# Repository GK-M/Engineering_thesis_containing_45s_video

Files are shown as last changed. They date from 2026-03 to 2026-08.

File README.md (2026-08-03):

# Diploma Thesis Repository

**Project and Implementation of a Microprocessor Platform for Building Distributed I/O Using a Selected Protocol Supported by Siemens S7-1200**

This repository contains my diploma thesis project focused on building a **distributed I/O platform** based on **Modbus TCP/IP**, where a **Siemens S7-1200 PLC** acts as the **Modbus client** and **ESP32 nodes** act as **Modbus servers**.

<p align="center">
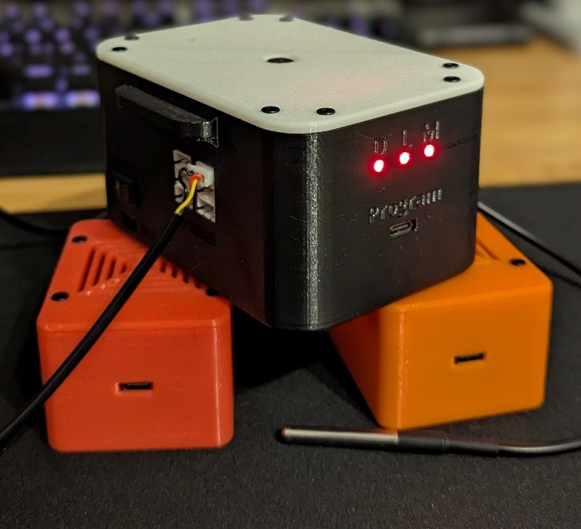
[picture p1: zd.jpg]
zd
  
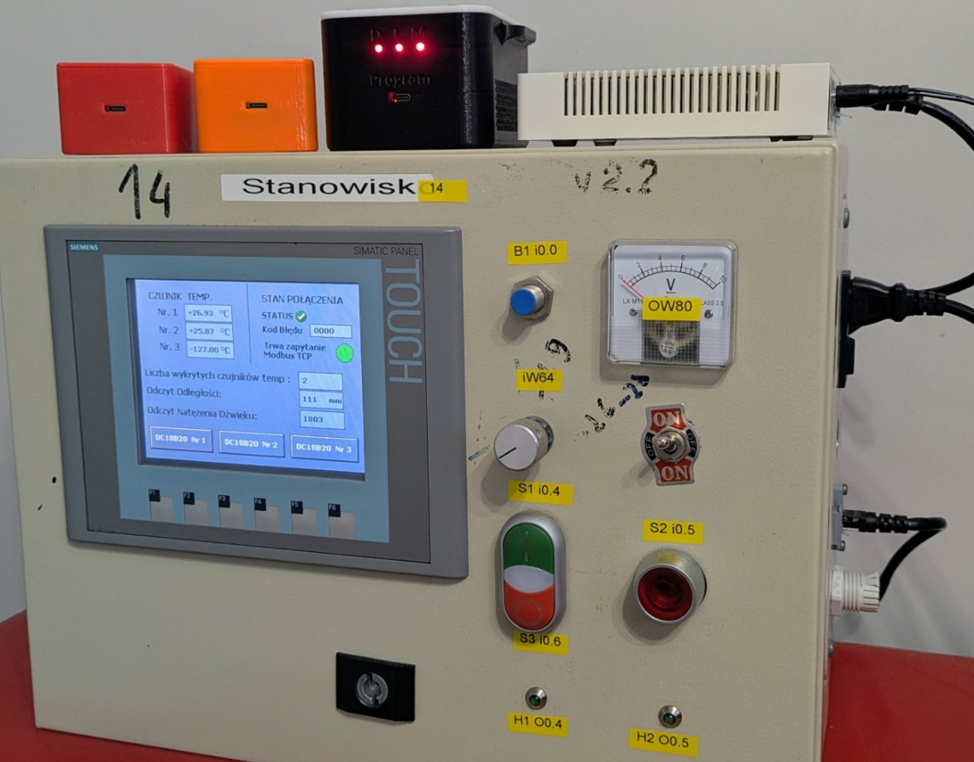
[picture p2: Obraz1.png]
Obraz1
  
</p>

## System concept
A local **LAN network** connects the PLC and multiple ESP32-based I/O nodes. Each ESP32 collects sensor data, performs basic local processing (min/max tracking, event detection), and exposes registers to the PLC via **Modbus TCP/IP**. The PLC then processes the data and presents it on an HMI.
## Video
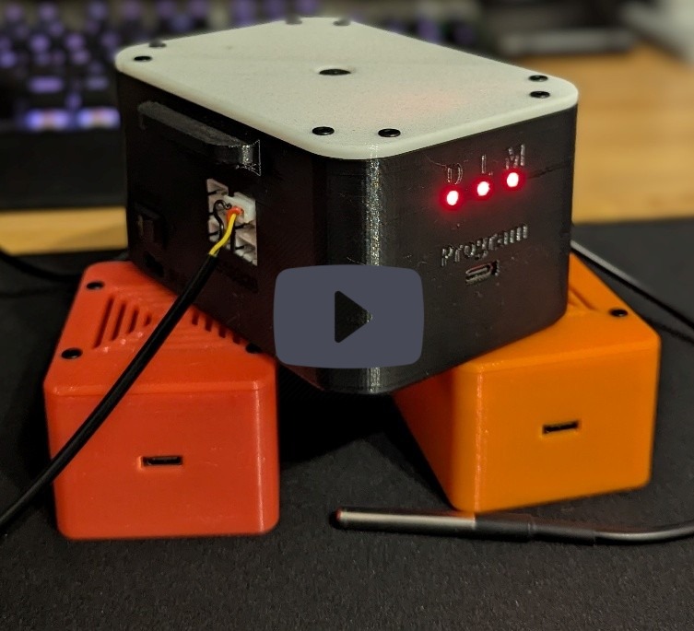
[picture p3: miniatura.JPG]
Oglądaj na YouTube (https://youtu.be/Fh-YvNaHG-w)


## ESP32 node functionalities

* **Temperature monitoring (DS18B20)**

  * Current temperature reading
  * Tracking and reporting **minimum** and **maximum** values
* **Acoustic event detection (MAX4466 microphone module)**

  * Detecting crack/pop-like impulse events
* **Production line part counting (VL53L1X ToF sensor)**

  * Counting items on a production line
  * Tracking **minimum** and **maximum** distance readings
* **Status signaling**

  * LED indicators for device state and detected events/conditions
* **Power redundancy**

  * Dual power supply: **wired power** and **battery backup**

## PLC and HMI implementation (S7-1200)

* Modbus TCP/IP **client** implementation to read/write ESP32 registers
* PLC program for data handling, scaling, alarms/limits, and diagnostics
* **HMI screens** to visualize measurements, counters, min/max values, and device status

## Mechanical and hardware work

* 3D modeling and fabrication of an **enclosure** for all Modbus server nodes
* Design of an **interconnection/interface board** for wiring and integration
* Preparation of **technical drawings** and documentation

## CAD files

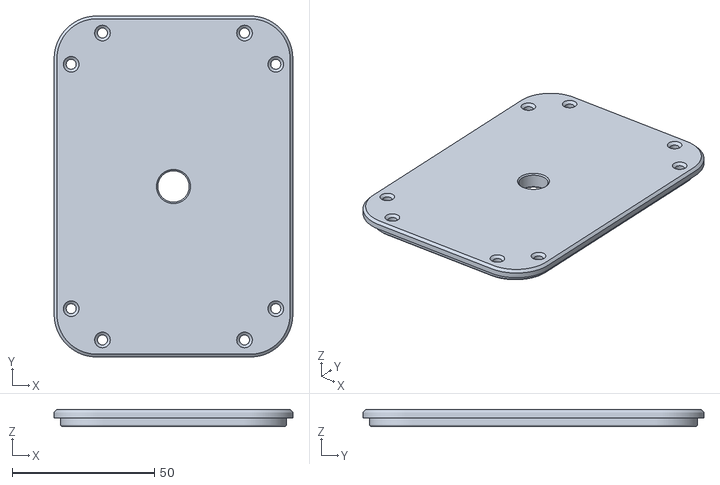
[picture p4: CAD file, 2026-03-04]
Modele 3D/Pokrywa_main_serwer.stl
84.0 x 120.0 x 6.00

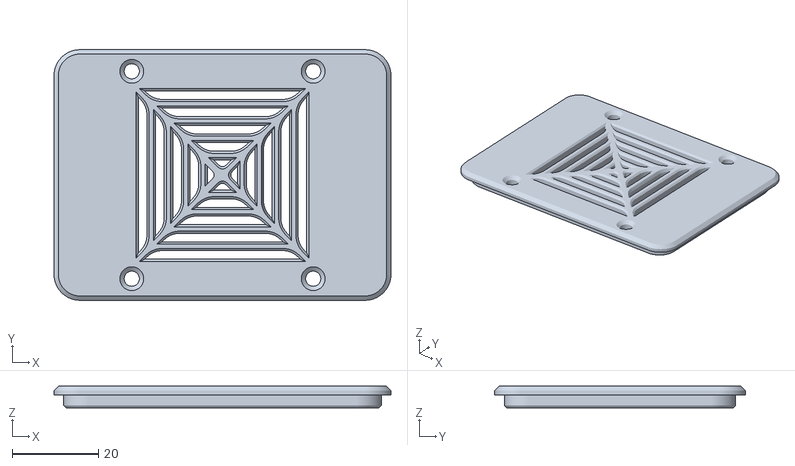
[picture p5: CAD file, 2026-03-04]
Modele 3D/Pokrywa_serwer.stl
78.0 x 58.0 x 5.00

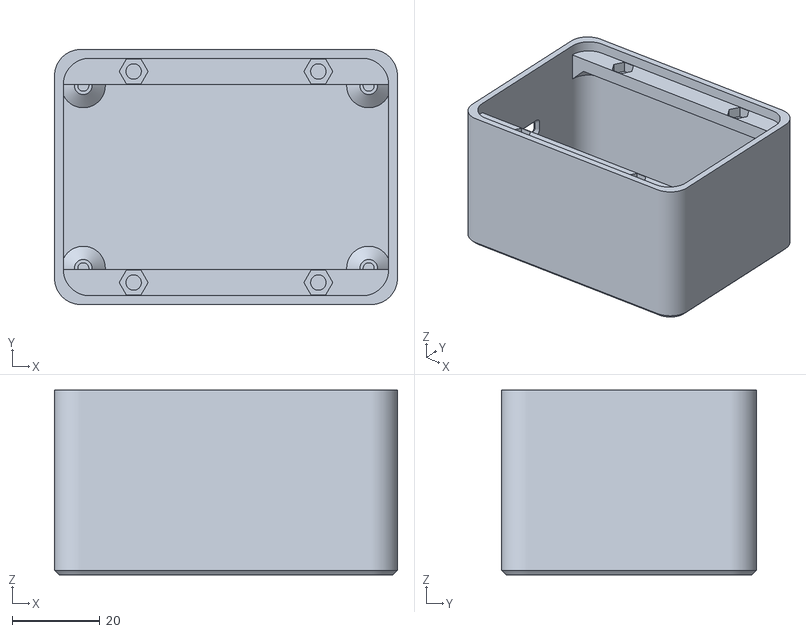
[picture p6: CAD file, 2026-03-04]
Modele 3D/Korpus_serwer.stl
78.0 x 58.0 x 42.0

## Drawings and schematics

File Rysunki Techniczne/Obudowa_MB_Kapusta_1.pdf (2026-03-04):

1

2

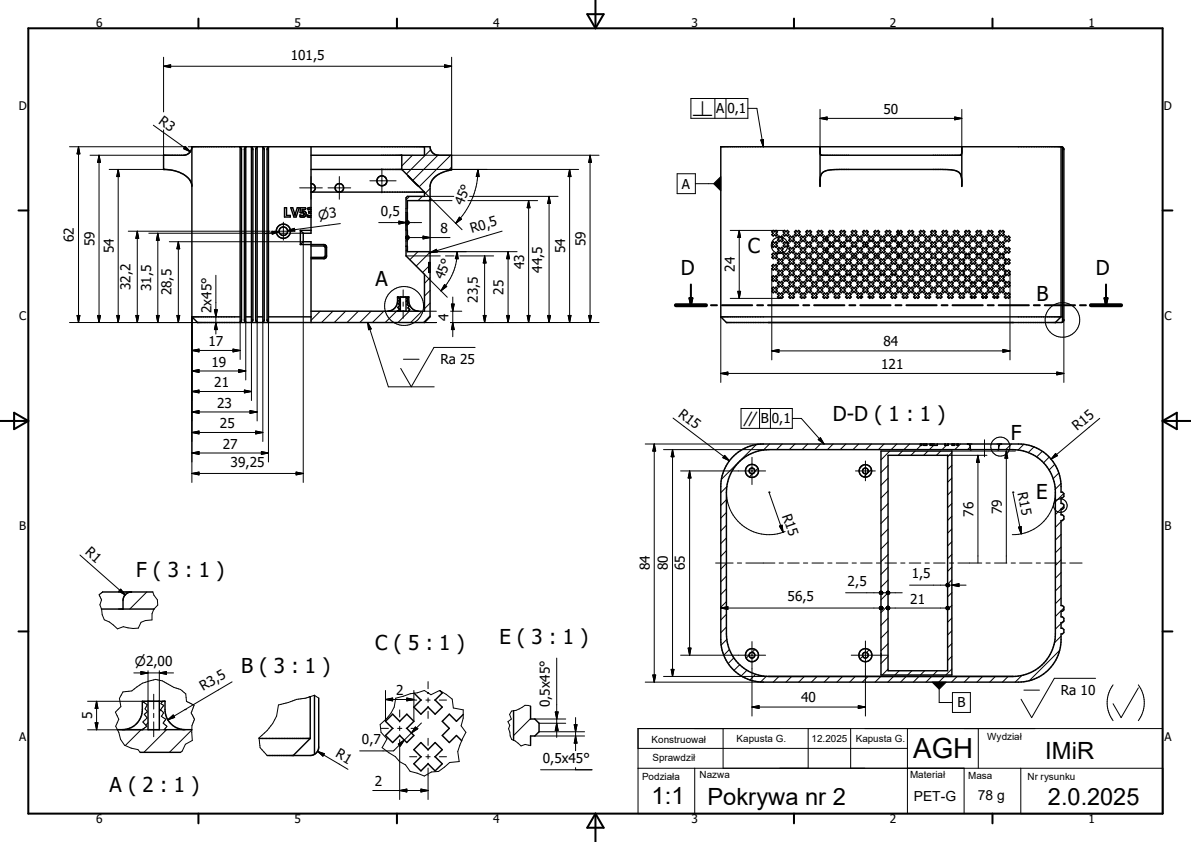
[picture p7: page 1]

Konstruował | Kapusta G. | 12.2025 | Kapusta G. | AGH | Wydział IMiR
Sprawdził
Podziała 1:1 | Nazwa Pokrywa nr 2 | Materiał PET-G | Masa 78 g | Nr rysunku 2.0.2025

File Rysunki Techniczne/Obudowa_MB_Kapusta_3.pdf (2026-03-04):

1

2

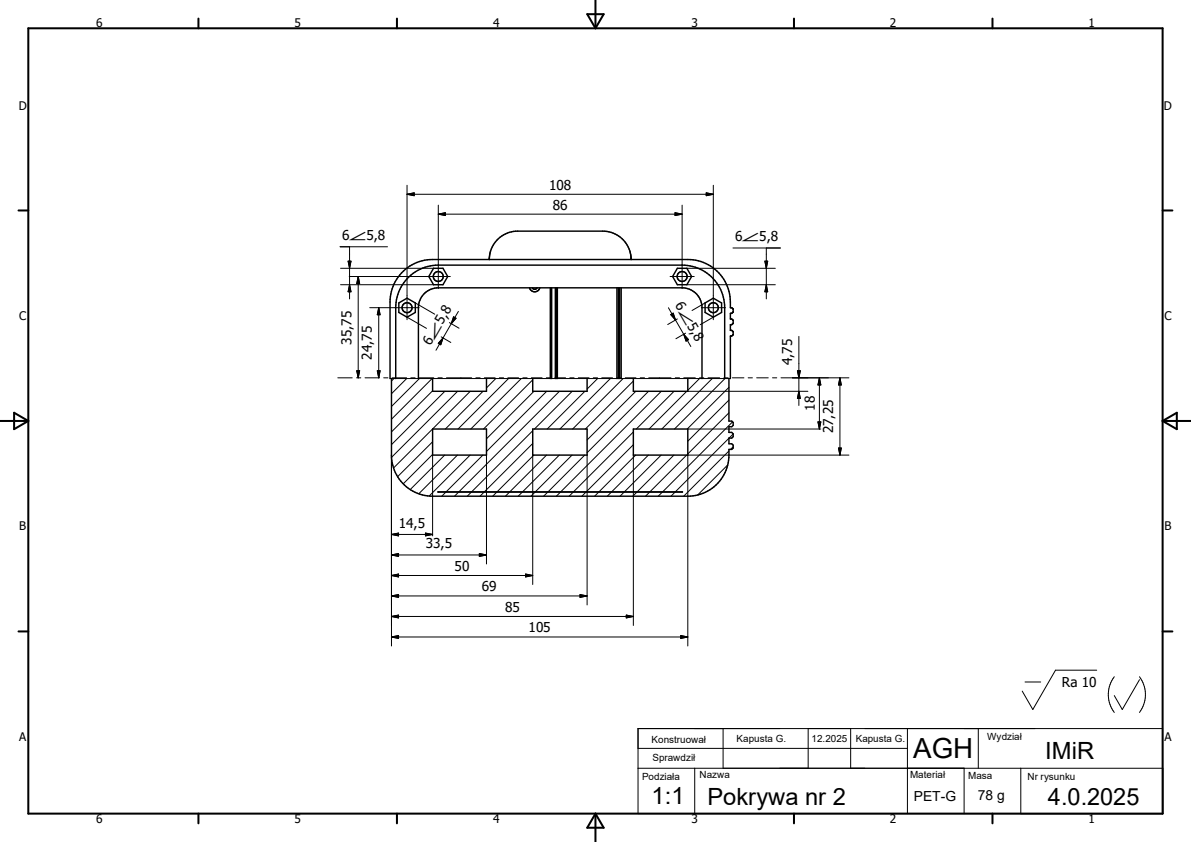
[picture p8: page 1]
Materiał ²⁴,75 35,75

Konstruował | Kapusta G. | 12.2025 | Kapusta G. | AGH | Wydział IMiR
Sprawdził
Podziała 1:1 | Nazwa Pokrywa nr 2 | PET-G | Masa 78 g | Nr rysunku 4.0.2025

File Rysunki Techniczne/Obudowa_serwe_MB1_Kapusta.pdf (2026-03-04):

1

2

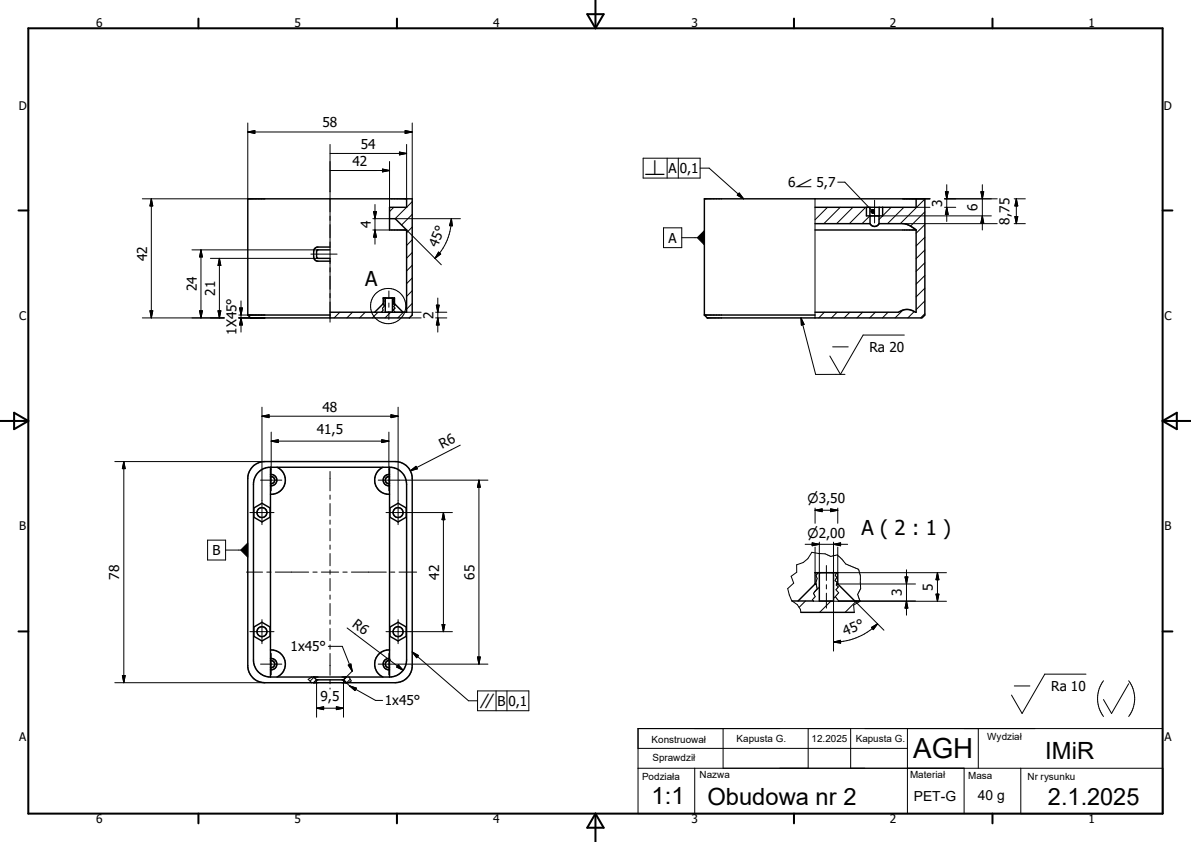
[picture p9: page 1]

Konstruował | Kapusta G. | 12.2025 | Kapusta G. | AGH | Wydział IMiR
Sprawdził
Podziała 1:1 | Nazwa Obudowa nr 2 | Materiał PET-G | Masa 40 g | Nr rysunku 2.1.2025

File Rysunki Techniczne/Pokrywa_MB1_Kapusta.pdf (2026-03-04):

78

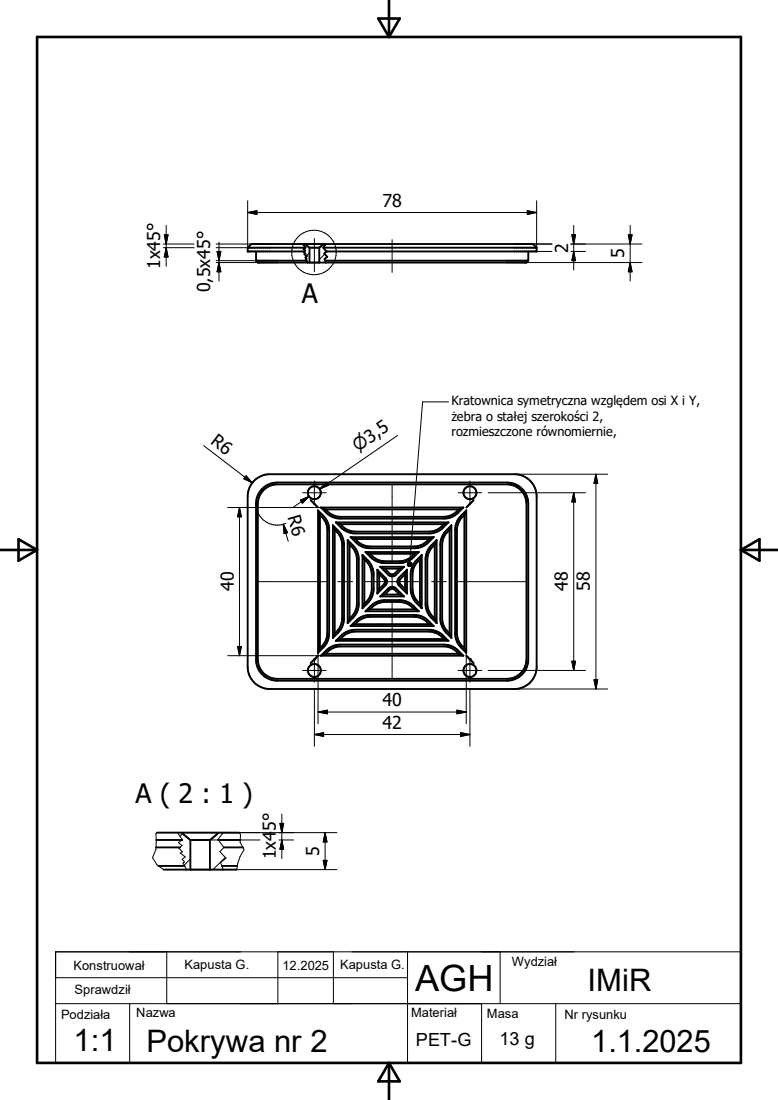
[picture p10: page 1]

Kratownica symetryczna względem osi X i Y,
żebra o stałej szerokości 2,
rozmieszczone równomiernie,

Konstruował | Kapusta G. | 12.2025 | Kapusta G. | AGH | Wydział IMiR
Sprawdził
Podziała 1:1 | Nazwa Pokrywa nr 2 | Materiał PET-G | Masa 13 g | Nr rysunku 1.1.2025

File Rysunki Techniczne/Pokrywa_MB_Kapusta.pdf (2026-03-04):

84

79

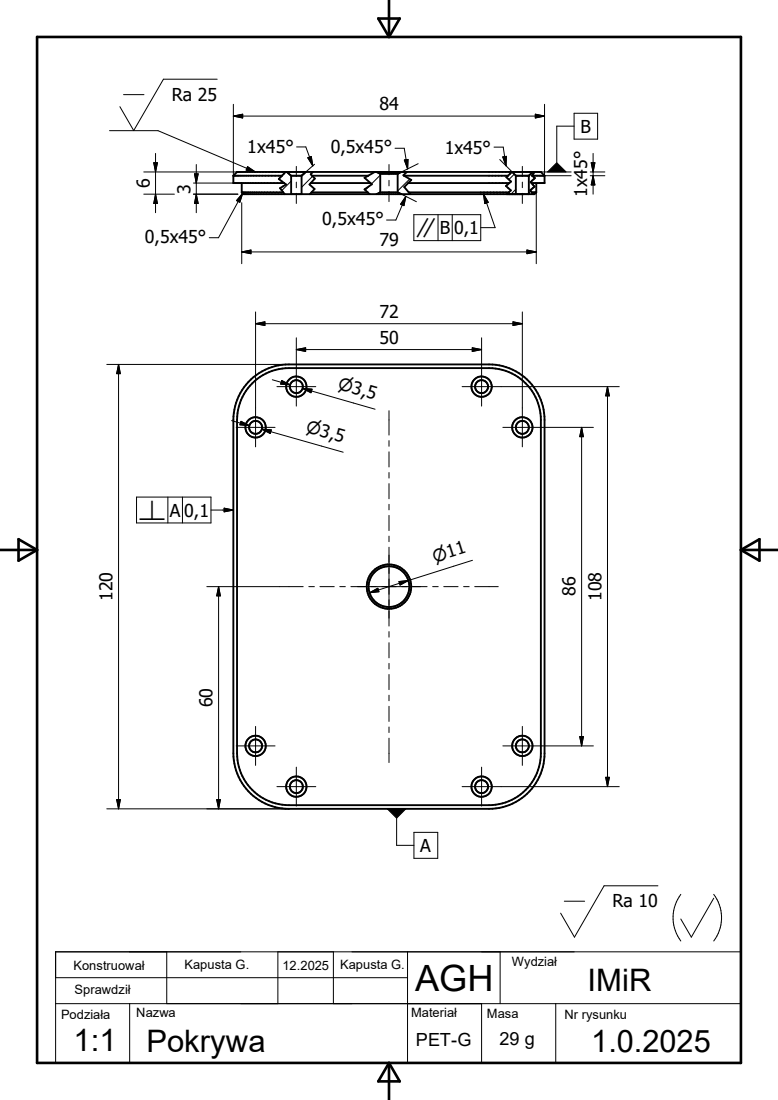
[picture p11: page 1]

Konstruował | Kapusta G. | 12.2025 | Kapusta G. | AGH | Wydział IMiR
Sprawdził
Podziała 1:1 | Nazwa Pokrywa | Materiał PET-G | Masa 29 g | Nr rysunku 1.0.2025

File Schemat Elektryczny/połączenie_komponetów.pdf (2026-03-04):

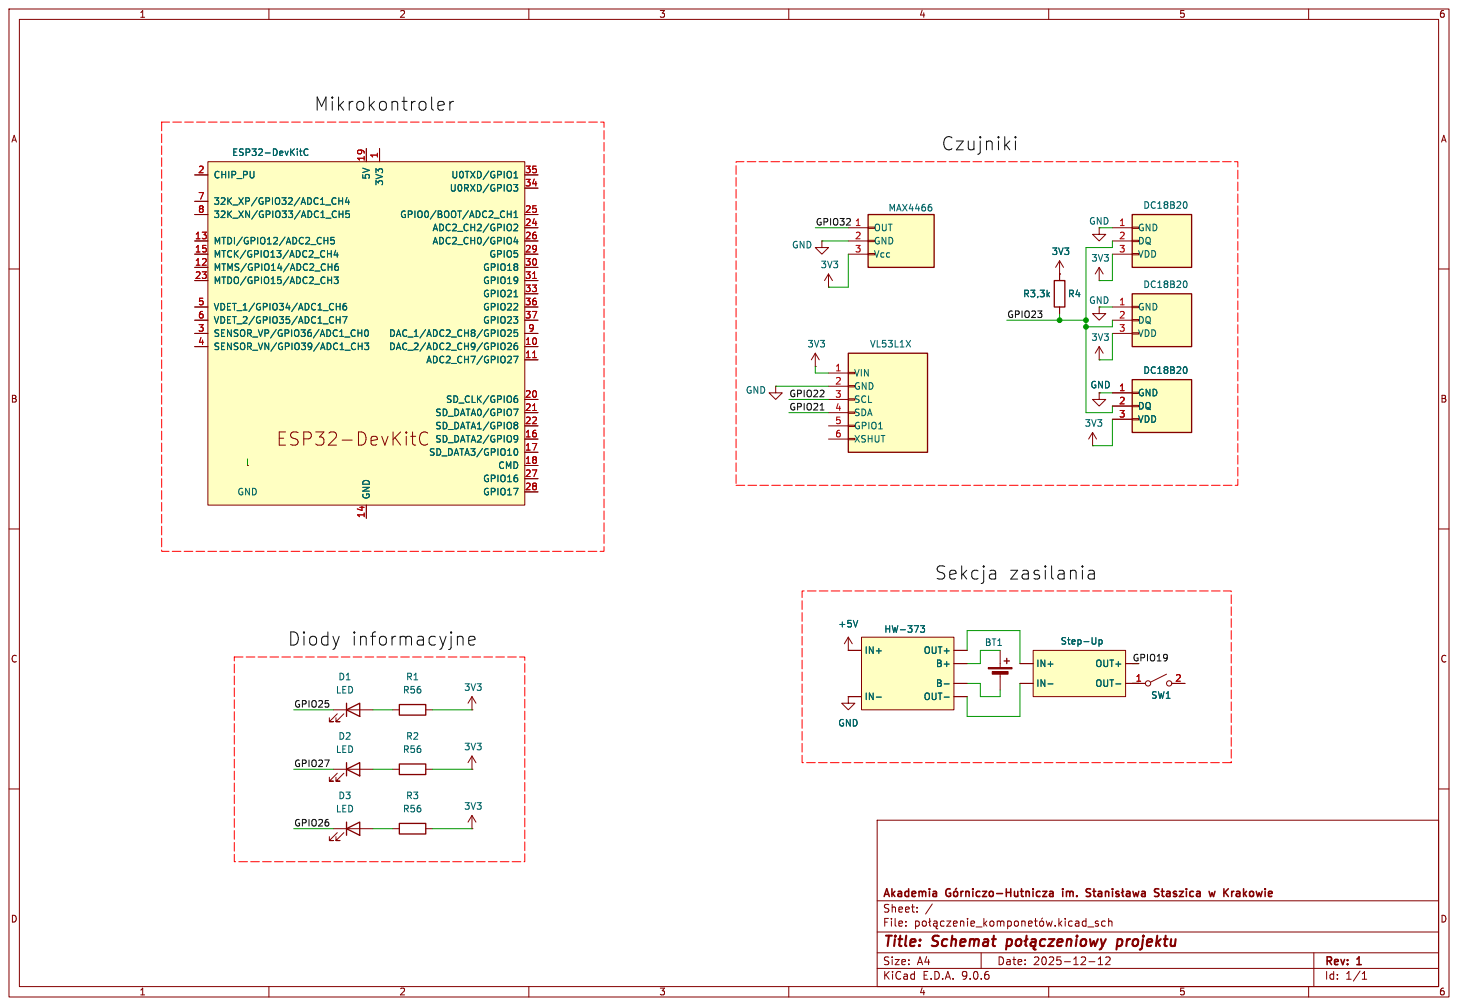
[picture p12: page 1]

Id: 1/1 Title: Schemat þÿpoBczeniowy projektu

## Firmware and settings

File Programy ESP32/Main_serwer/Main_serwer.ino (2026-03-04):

#include <Arduino.h>
//Biblioteki do DS18B20
#include <OneWire.h>
#include <DallasTemperature.h>

//Biblioteka do I2C
#include <Wire.h>
#include <Adafruit_VL53L1X.h>

//Biblioteka Modbus TCP/IP
#include <ModbusIP_ESP8266.h>        

#define SDA_PIN 21       // VL53L1 SDA
#define SCL_PIN 22       // VL53L1 SCL
#define ONE_WIRE_PIN 23  // DS18B20
#define MAX_PIN 32       //MAX4466
#define MAX_LED 26
#define ONE_WIRE_LED 25
#define VL_LED 27


#include <WiFi.h>

bool PokazOdleglosc = LOW;
bool PokazTemp = LOW;
bool PokazMinMaxTemp = LOW;
bool AlarmCzujniaTemp = LOW;

const char* ssid = "MikroTik";     // Nazwa sieci WiFi
const char* pass = "12345678";    // Haslo sieci WiFi

IPAddress local_IP(192,168,0,253);  // Adres IP ESP32
IPAddress gateway(192,168,0,1);      // IP rutera
IPAddress subnet(255,255,255,0);     // Maska sieci


// Modbus 
ModbusIP mb;    // obiekt Modbus TCP (port 502 domyślnie)

//Ustawienie Adresów Modbus
const uint16_t REG_TEMP_1 = 0;  // Adress czujnik temperatury 1  => w PLC to 40001 
const uint16_t REG_TEMP_2 = 1;  // Adress czujnik temperatury 2  => w PLC to 40002 
const uint16_t REG_TEMP_3 = 2;  // Adress czujnik temperatury 3  => w PLC to 40003 
const uint16_t REG_VL     = 3;

const uint16_t REG_Alarm_1 = 4;
const uint16_t REG_Alarm_2 = 5;
const uint16_t REG_Alarm_3 = 6;

const uint16_t REG_HMI_D1_ERROR = 7;
const uint16_t REG_HMI_D2_ERROR = 8;
const uint16_t REG_HMI_D3_ERROR = 10;

const uint16_t REG_MaxDS_1 = 11;
const uint16_t REG_MinDS_1 = 12;

const uint16_t REG_MaxDS_2 = 13;
const uint16_t REG_MinDS_2 = 14;

const uint16_t REG_MaxDS_3 = 15;
const uint16_t REG_MinDS_3 = 16;

const uint16_t REG_IleCzujnikow = 17;
const uint16_t REG_Alarm_VL = 18;
const uint16_t REG_IleDetali = 19;

const uint16_t REG_VLMaxPomiar  = 20;
const uint16_t REG_VLMinPomiar  = 21;
const uint16_t REG_MaxAnalowgowyOdczyt = 22;
const uint16_t REG_MaxOdczytFiltr = 23;
const uint16_t REG_PrzekroczenieWartosc = 24;
const uint16_t REG_MaxAlarm = 25;




//Czujnik VL53L1
uint16_t distance_mode = 1; //distance mode (1=short, 2=long).
int I2C_Speed = 400000; // Hz

Adafruit_VL53L1X vl = Adafruit_VL53L1X(); 

uint16_t V1budget = 100;  //Budget pomiarowy 
uint16_t V1SamplingTime = 150; // Co ile pomiar 
int16_t mm = 0;
bool Alarm_VL = LOW;
uint16_t poprzednie_mm = 0;
uint16_t IleDetali = 0;
uint16_t OdlegloscDetal = 0;
bool FlagaDetal = HIGH;
uint16_t MaxPomiar = 0;
uint16_t MinPomiar = 10000;

uint32_t VL_CzasAktualny = 0;
uint32_t VL_CzasPomoc = 0;
uint16_t VL_CzasPotwierdzenie = 500;




// Utworzenie obiektu OneWire i DallasTemperature
OneWire oneWire(ONE_WIRE_PIN);
DallasTemperature sensors(&oneWire);

//Flaga pomocnicza do ponownego uruchomienia OneWire
bool Flaga_mm = HIGH;

//Adresy czujników DS18B20
int LiczbaDS18 = 0;

DeviceAddress Adresy[3]={
{0x28,0x20,0xC4,0xBC,0x00,0x00,0x00,0x16},
{0x28,0x85,0x64,0xBC,0x00,0x00,0x00,0x92},
{0x28,0xFF,0x64,0x1F,0x69,0xAB,0x7B,0xDA}
};

//Odczyt co ile z czujników
uint32_t DS_czas_pomiar = 500;  // pomiar temperatury co 500ms
uint32_t DS_czas_pomoc_pomiar = 0;

//Pomocnicze DC18B20
bool konwersjaTrwa = LOW;

//Temperatury Graniczne dla wszystkich czujników
int16_t TempZaWysoka = 80;
int16_t TempZaNiska = -10;

//Max i Min Temp dla czujników:
int16_t MaxDS_1 = -5600;
int16_t MinDS_1 = 12700;

int16_t MaxDS_2 = -5600;
int16_t MinDS_2 = 12700;

int16_t MaxDS_3 = -5600;
int16_t MinDS_3 = 12700;

struct Limit{
  int32_t pMax = -10000;
  int32_t pMin = 100000;
};

Limit limit[3];
  

//Alarmy granicznych Temp
bool Alarm_1 = LOW;
bool Alarm_2 = LOW;
bool Alarm_3 = LOW;

//Zmienne Temperatura
float DS_1 =  0.0;
float DS_2 =  0.0;
float DS_3 =  0.0;

int16_t DS_1x100 = 12701;
int16_t DS_2x100 = 12701;
int16_t DS_3x100 = 12701;

//HMI błąd czujnika

bool HMI_D1_ERROR = LOW;
bool HMI_D2_ERROR = LOW;
bool HMI_D3_ERROR = LOW;

//Zmienne Max4466

int16_t MaxAnalowgowyOdczyt = 0;
const uint16_t MaxProgWykrycia = 1800; 
int16_t MaxLiniaOdniesienia = 4096/2;
int16_t MaxOdczytFiltr = 0;
int32_t CzasMaxOdczyt = 0;
int32_t CzasMaxOdczytPomoc = 0;
uint8_t TrwanieDzwieku = 5;
bool MaxAlarm = LOW; //LOW
uint8_t PrzekroczenieWartosc = 0;

int32_t CzasZgloszenie = 0;
int32_t pCzasZgloszenie = 0;
int8_t IleOdczekac = 10;

uint32_t CzasAlarmMAX = 0;
uint32_t pCzasAlarmMAX = 0;

//Ledy:
  struct Led {
  bool StanLed = HIGH;
  bool StanLeD = HIGH;
  uint32_t Pomocled = 0;
  uint32_t mocLED = 0;
  uint32_t PomocledNara = 0;
  uint32_t LedDuble_millis = 0;
  uint32_t PomocledDuble = 0;
  int a =0;
  bool LedOnoFF = HIGH;
  uint32_t TimeWaitDuble = 300;
};

 Led leds[3];

uint32_t Led_millis = 0;
const uint32_t TimeWait = 200;  // Co ile miga
uint32_t NarastanieTime = 0;
const uint32_t TimeWaitNaras = 5; 
uint32_t LedDuble_millis = 0;
//bool LedOnoFF = HIGH;
uint32_t TimeWaitDuble = 300;


//Możliwe Stany Czujnikow / ledy

 enum StanCzujnikow {     
  DS18b20_NOK = 1 << 0,  // 0001
  VL_NOK      = 1 << 1,  // 0010
  MAX_NOK     = 1 << 2,   // 0100
};



// zmienne inne
int sprawdzam = 0;
bool Bylo1 = HIGH;
bool Bylo2 = HIGH;
bool Bylo3 = HIGH;
bool Bylo4 = HIGH;
bool Bylo5 = HIGH;
bool Bylo6 = HIGH;
bool Bylo7 = HIGH;
bool Bylo8 = HIGH;

void ResetLedow(){
    for(int i = 0; i < 3; i++){   
    leds[i].Pomocled = 0;
    leds[i].StanLed = HIGH;
    leds[i].StanLeD= HIGH;
    leds[i].mocLED = 0;
    leds[i].PomocledNara = 0;
    //leds[i].LedDuble_millis = 0;
    leds[i].PomocledDuble = 0;
    leds[i].a = 0;
    leds[i].LedOnoFF = HIGH;
    leds[i].TimeWaitDuble = 300;
    }
  Led_millis = 0;
  NarastanieTime = 0;
  LedDuble_millis = 0;
  TimeWaitDuble = 300;

    }
    //digitalWrite(MAX_LED, 0);
    //digitalWrite(ONE_WIRE_LED, 0);
    //digitalWrite(VL_LED, 0);
    //delay(100);


void ONE_WIRE_DS() {
  uint32_t DS_czas = millis();
  if (DS_czas - DS_czas_pomoc_pomiar >= DS_czas_pomiar && !konwersjaTrwa) {
      DS_czas_pomoc_pomiar = DS_czas;
      sensors.requestTemperatures();        // rozpocznij pomiar
      konwersjaTrwa = HIGH;
  }
  if (sensors.isConversionComplete() && konwersjaTrwa){ //Czy sensor jest gotowy na odczyt

    DS_1 = sensors.getTempC(Adresy[0]);   // pierwszy czujnik
    DS_2 = sensors.getTempC(Adresy[1]);    // drugi czujnik
    DS_3 = sensors.getTempC(Adresy[2]);    // trzeci czujnik

    DS_1x100 = DS_1 * 100; // Pomiary z czujników pomnożone przez 100
    DS_2x100 = DS_2 * 100;
    DS_3x100 = DS_3 * 100;
    konwersjaTrwa = LOW;

    if(PokazTemp == HIGH){
    Serial.printf("DS1: %.2f", DS_1);
    Serial.println("C");
    Serial.printf("DS2: %.2f", DS_2);
    Serial.println("C");
    Serial.printf("DS3: %.2f", DS_3);
    Serial.println("C");
      }
    }

    if(mm !=-1 && mm <= 10 && Flaga_mm){
      sensors.begin();
      LiczbaDS18 = sensors.getDeviceCount();
      Serial.printf("Wykryto: %d czujniki \n",LiczbaDS18);
      Flaga_mm = LOW;
    }
    else Flaga_mm = HIGH;
    
    if(PokazTemp == HIGH){
    Serial.printf("DS1: %.2f", DS_1);
    Serial.println("C");
    Serial.printf("DS2: %.2f", DS_2);
    Serial.println("C");
    Serial.printf("DS3: %.2f", DS_3);
    Serial.println("C");
   }
       
}

void ZapiszMinTemp(float odczyt, int16_t odczytX100,  int16_t *Min, int a,DeviceAddress Adres){

 if (*Min > odczytX100 && odczyt != -127.00){
      *Min = odczytX100;

        if(PokazMinMaxTemp) {
        if(*Min < limit[a].pMin){
          Serial.printf("Minimalna Temperatura czujnika %d : %d \n",Adres,HEX, *Min);
          if(odczyt != -127.00){
            limit[a].pMin = *Min;
          }
          else{
              limit[a].pMin = 0;
          }
          }
          
        }
      }
    }

void ZapiszMaxTemp(float odczyt, int16_t odczytX100, int16_t *Max, int a,DeviceAddress Adres){

  if (*Max < odczytX100 && odczyt != -127.00 && odczytX100 != 12701 && odczyt != 85.00){
      *Max = odczytX100;
      
      if(PokazMinMaxTemp){
        
      if(*Max > limit[a].pMax ){
        Serial.printf("Maksymalna Temperatura czujnika %d : %d \n",Adres, *Max);
        if(odczyt != -127.00){
          limit[a].pMax = *Max;
        }
        else{
          limit[a].pMax = 0;
        }
      }
     }  
    }
} 


void BladCzujnikaTempHMI(float czujnikpomiar, bool *FlagaDlaCzujnika){

    if ( czujnikpomiar == -127.00){
        *FlagaDlaCzujnika = HIGH;
    } 
    else {
      *FlagaDlaCzujnika = LOW;
    }
}
    //85.00 - brak konwersji domyśla wartość czujnika DS18b20
    //-127.000 - błąd komunikacji / brak czujnika

void AlarmTemp(DeviceAddress Adres, bool *StanAlarmu, float odczyt){

     if (sensors.hasAlarm(Adres) && odczyt != -127.00 && odczyt != +85.0){
      *StanAlarmu = HIGH;
      Serial.printf("%f \n",odczyt);
      if(AlarmCzujniaTemp){
        Serial.printf("%f \n",odczyt);
        Serial.printf("Alarm Czujnika: %d \n",Adres);
      } 
    }
     
   
    else *StanAlarmu = LOW;
  }


void DubleBlink(int LED, int idx){
   LedDuble_millis = millis();
  
  if (LedDuble_millis - leds[idx].PomocledDuble > leds[idx].TimeWaitDuble && leds[idx].a < 4) {
    leds[idx].PomocledDuble = LedDuble_millis;
    leds[idx].StanLed = !leds[idx].StanLed;
    digitalWrite(LED, leds[idx].StanLed);
    leds[idx].a = leds[idx].a + 1;
    leds[idx].TimeWaitDuble = 300;
  }
  else if (LedDuble_millis - leds[idx].PomocledDuble > leds[idx].TimeWaitDuble && leds[idx].a==4){
    leds[idx].PomocledDuble = LedDuble_millis;
    leds[idx].StanLed = HIGH;
    digitalWrite(LED, leds[idx].StanLed);
    leds[idx].TimeWaitDuble = 600;
    leds[idx].a=0;
  }
  //Serial.println(leds[idx].a);
 }
void NarastanieLED(int LED, int idx){

  NarastanieTime = millis();

  if(NarastanieTime - leds[idx].PomocledNara > TimeWaitNaras){
      leds[idx].PomocledNara = NarastanieTime;

    if (leds[idx].mocLED <= 255 && leds[idx].LedOnoFF){
        leds[idx].mocLED = 2 + leds[idx].mocLED;
        analogWrite(LED,leds[idx].mocLED);
        if (leds[idx].mocLED >= 256){
          leds[idx].LedOnoFF=!leds[idx].LedOnoFF;
        }
      }

      else if (!leds[idx].LedOnoFF){

        if (leds[idx].mocLED > 0){
        leds[idx].mocLED = leds[idx].mocLED - 2;
        analogWrite(LED,leds[idx].mocLED);
        if (leds[idx].mocLED <= 0){
          leds[idx].LedOnoFF=!leds[idx].LedOnoFF;
        }
      }
    }
    }
  }
void blinking_led(int LED, int idx) {

  Led_millis = millis();
  if (LedDuble_millis  - leds[idx].Pomocled > TimeWait) {
    leds[idx].Pomocled = LedDuble_millis ;

    leds[idx].StanLeD = !leds[idx].StanLeD;
    digitalWrite(LED, leds[idx].StanLeD);
  }

 }

void LedyError(){

  static uint8_t ostatniStan = 255; // cos spoza zakresu 0..7 na start
  bool ds_nok = LOW;
  bool v1_nok  = LOW;
  bool max_nok = LOW;
  uint8_t stan = 0;
  

  
    if (DS_1 == -127.00 || DS_2 == -127.00 || DS_3 == -127.00 ) ds_nok = HIGH;
    if (mm == -1) v1_nok = HIGH; 
    if(MaxAlarm) max_nok = HIGH; 

    if (ds_nok ) {
      stan |= DS18b20_NOK;  // ustaw bit 0
    }  
    if (v1_nok  ){
      stan |= VL_NOK;   // ustaw bit 1
    }        
    if (MaxAlarm  ){
      stan |= MAX_NOK;     // ustaw bit 2
    } 


 // restart przy zmianie stanu ledów
  if (stan != ostatniStan ) {
    //Serial.println("Restart diod");
    ResetLedow();
    ostatniStan = stan;

  }

 //Serial.println(stan);
    
  /*
  if(stan == 0b0001 && Bylo2 == HIGH && Bylo3 == HIGH && Bylo4 == HIGH && Bylo5 == HIGH && Bylo6 == HIGH && Bylo7 == HIGH && Bylo8 == HIGH){
    Bylo1 = LOW;
  }
  else if (stan == 0b0010 && Bylo1 == HIGH && Bylo3 == HIGH && Bylo4 == HIGH && Bylo5 == HIGH && Bylo6 == HIGH && Bylo7 == HIGH && Bylo8 == HIGH){
    Bylo2 = LOW;
  }
  else if (stan == 0b0100 && Bylo1 == HIGH && Bylo2 == HIGH && Bylo4 == HIGH && Bylo5 == HIGH && Bylo6 == HIGH && Bylo7 == HIGH && Bylo8 == HIGH){
    Bylo3 = LOW;
  }
  else if (stan == 0b0111 && Bylo1 == HIGH && Bylo2 == HIGH && Bylo3 == HIGH && Bylo5 == HIGH && Bylo6 == HIGH && Bylo7 == HIGH && Bylo8 == HIGH){
    Bylo4 = LOW;
  }
  else if (stan == 0b0110 && Bylo1 == HIGH && Bylo2 == HIGH && Bylo3 == HIGH && Bylo4 == HIGH && Bylo6 == HIGH && Bylo7 == HIGH && Bylo8 == HIGH){
    Bylo5 = LOW;
  }
  else if (stan == 0b0101 && Bylo1 == HIGH && Bylo2 == HIGH && Bylo3 == HIGH && Bylo4 == HIGH && Bylo5 == HIGH && Bylo7 == HIGH && Bylo8 == HIGH){
    Bylo6 = LOW;
  }
  else if (stan == 0b0011 && Bylo1 == HIGH && Bylo2 == HIGH && Bylo3 == HIGH && Bylo4 == HIGH && Bylo5 == HIGH && Bylo6 == HIGH && Bylo8 == HIGH){
    Bylo7 = LOW;
  }
  else if (stan == 0b0000 && Bylo1 == HIGH && Bylo2 == HIGH && Bylo3 == HIGH && Bylo4 == HIGH && Bylo5 == HIGH && Bylo6 == HIGH && Bylo7 == HIGH){
    Bylo8 = LOW;
  }
  else {
    if (Bylo1 == LOW || Bylo2 == LOW || Bylo3 == LOW || Bylo4 == LOW || Bylo5 == LOW || Bylo6 == LOW || Bylo7 == LOW || Bylo8 == LOW) {
    Serial.println("Restart");
    ResetLedow();   
    Bylo1 = HIGH;
    Bylo2 = HIGH;
    Bylo3 = HIGH; 
    Bylo4 = HIGH;
    Bylo5 = HIGH;  
    Bylo6 = HIGH;
    Bylo7 = HIGH;
    Bylo8 = HIGH;
    return;
    }

  }
   */ 
    switch (stan) {

      case DS18b20_NOK: 
        blinking_led(ONE_WIRE_LED, 1);
        DubleBlink(MAX_LED, 0);
        DubleBlink(VL_LED, 2);
        break;

      case VL_NOK: 
        DubleBlink(ONE_WIRE_LED, 1);
        blinking_led(VL_LED, 2);
        DubleBlink(MAX_LED, 0);
        break;

      case MAX_NOK: 
        DubleBlink(ONE_WIRE_LED, 1);
        DubleBlink(VL_LED, 2);
        blinking_led(MAX_LED, 0);;
        break;

      case DS18b20_NOK | VL_NOK:
        blinking_led(ONE_WIRE_LED, 1);
        blinking_led(VL_LED, 2);
        DubleBlink(MAX_LED, 0);
        break;

      case DS18b20_NOK | MAX_NOK:
        blinking_led(ONE_WIRE_LED, 1);
        DubleBlink(VL_LED, 2);
        blinking_led(MAX_LED, 0);
        break;

      case VL_NOK | MAX_NOK:
        DubleBlink(ONE_WIRE_LED, 1);
        blinking_led(VL_LED, 2);
        blinking_led(MAX_LED, 0);
        break;

      case DS18b20_NOK | VL_NOK | MAX_NOK:
      Serial.println("wszystkieNOK");
        blinking_led(ONE_WIRE_LED, 1);
        blinking_led(VL_LED, 2);
        blinking_led(MAX_LED, 0);
        break;

      default:
        DubleBlink(MAX_LED, 0);
        DubleBlink(ONE_WIRE_LED, 1);
        DubleBlink(VL_LED, 2);
        break;

      }
    }

/*
void LedyError(){

    if((DS_1 == -127.00 || DS_2 == -127.00 || DS_3 == -127.00) && mm != -1 && Bylo2 == HIGH && Bylo3 == HIGH && !MaxAlarm) { 
    blinking_led(ONE_WIRE_LED, 1);
    DubleBlink(MAX_LED, 0);
    DubleBlink(VL_LED, 2);
    Bylo1 = LOW;
  }
  else if (mm == -1 && !(DS_1 == -127.00 || DS_2 == -127.00 || DS_3 == -127.00) && Bylo1 == HIGH && Bylo3 == HIGH && !MaxAlarm){
    DubleBlink(ONE_WIRE_LED, 1);
    DubleBlink(MAX_LED, 0);
    blinking_led(VL_LED, 2);
    Bylo2 = LOW;
  }
  else if (mm == -1 && (DS_1 == -127.00 || DS_2 == -127.00 || DS_3 == -127.00) && Bylo2 == HIGH && Bylo1 == HIGH && !MaxAlarm){
    blinking_led(ONE_WIRE_LED, 1);
    DubleBlink(MAX_LED, 0);
    blinking_led(VL_LED, 2);
    Bylo3 = LOW;
  }
  else if(mm == -1 && !(DS_1 == -127.00 || DS_2 == -127.00 || DS_3 == -127.00) && Bylo2 == HIGH && Bylo1 == HIGH && !MaxAlarm){
    blinking_led(ONE_WIRE_LED, 1);
    DubleBlink(MAX_LED, 0);
    blinking_led(VL_LED, 2);

  }
  else {
  if(Bylo1 == LOW ){
    ResetLedow();
    Bylo1 = HIGH;
  }
  else if(Bylo2 == LOW ){
    ResetLedow();
    Bylo2 = HIGH;
    }
  else if (Bylo3 == LOW ){
    ResetLedow();
    Bylo3 = HIGH;
    }   
      DubleBlink(MAX_LED, 0);
      DubleBlink(ONE_WIRE_LED, 1);
      DubleBlink(VL_LED, 2);
    }

}
*/

void V1_Pomiar() {
    
  poprzednie_mm = mm;

  if (vl.dataReady()) {
    mm = vl.distance();          // odległość w mm
    vl.clearInterrupt();         // wyczyść flagę gotowości

    if (mm == -1) {

      if (PokazOdleglosc == HIGH) Serial.println("Błąd pomiaru");
      

      Alarm_VL = HIGH;
    } else {
      if (PokazOdleglosc == HIGH) Serial.printf("Odległość: %d mm\n", mm);
      
      
      Alarm_VL = LOW;
     }
    }

  //Liczenie Detali 
  if (abs(mm - poprzednie_mm) < 50 && abs(mm - poprzednie_mm) > 10 && FlagaDetal && mm != -1){
    VL_CzasAktualny = millis();
    if(VL_CzasAktualny - VL_CzasPomoc  >= 600 && abs(mm - poprzednie_mm) < 50){
      VL_CzasPomoc = VL_CzasAktualny;
      IleDetali ++;
      FlagaDetal = LOW;
      OdlegloscDetal = mm;

    if (PokazOdleglosc == HIGH) Serial.printf("Liczba Detali: %d \n" ,IleDetali);

      }
  }
  if (abs(mm - OdlegloscDetal) > 50 && mm != -1){
    FlagaDetal = HIGH;
  }
  
  //Max Odległość
  if ( mm >  MaxPomiar && mm != -1){
    MaxPomiar = mm;
    Serial.printf("Maksymalny Pomiar : %d \n" ,MaxPomiar);
  }
  //Min Odległość
  if (mm < MinPomiar && mm != -1 && MinPomiar != MaxPomiar){
    MinPomiar = mm;
    Serial.printf("Minimalny Pomiar: %d \n" ,MinPomiar);
  }





 }


void MAX4466_pomiar(){

  CzasMaxOdczyt = millis();
 
 if((CzasMaxOdczyt - CzasMaxOdczytPomoc) > TrwanieDzwieku ){
    CzasMaxOdczytPomoc = CzasMaxOdczyt;
    MaxAnalowgowyOdczyt = analogRead(MAX_PIN);
    MaxOdczytFiltr = abs(MaxAnalowgowyOdczyt - MaxLiniaOdniesienia );
    CzasZgloszenie = millis();
    
    if(MaxOdczytFiltr >= MaxProgWykrycia && CzasZgloszenie - pCzasZgloszenie >= IleOdczekac ){
      pCzasZgloszenie = CzasZgloszenie;
      PrzekroczenieWartosc = PrzekroczenieWartosc + 1;
      Serial.printf("Wykryto trzask o wartości: %d \n ",MaxOdczytFiltr);
    }
  }
    CzasAlarmMAX = millis();
  if(MaxAnalowgowyOdczyt == 0 && CzasAlarmMAX - pCzasAlarmMAX > 100) {
    MaxAlarm = HIGH;
    pCzasAlarmMAX =CzasAlarmMAX;
  }
  else MaxAlarm = LOW;
 }
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
void loop() {

  if(WiFi.status() != 3){

    WiFi.reconnect(); 
    NarastanieLED(MAX_LED, 0); 
    NarastanieLED(ONE_WIRE_LED, 1);
    NarastanieLED(VL_LED, 2);
    //Serial.print(".");
    //delay(200);
    Bylo1 = LOW;
    
  }
  else{
  LedyError();

  ONE_WIRE_DS();

  AlarmTemp(Adresy[0], &Alarm_1,DS_1);
  AlarmTemp(Adresy[1], &Alarm_2,DS_2);
  AlarmTemp(Adresy[2], &Alarm_3,DS_3);

  ZapiszMinTemp(DS_1, DS_1x100, &MinDS_1,0,Adresy[0]);
  ZapiszMinTemp(DS_2, DS_2x100, &MinDS_2,1,Adresy[1]);
  ZapiszMinTemp(DS_3, DS_3x100, &MinDS_3,2,Adresy[2]);

  ZapiszMaxTemp(DS_1, DS_1x100, &MaxDS_1, 0,Adresy[0]);
  ZapiszMaxTemp(DS_2, DS_2x100, &MaxDS_2, 1,Adresy[1]);
  ZapiszMaxTemp(DS_3, DS_3x100, &MaxDS_3, 2,Adresy[2]);
  

  BladCzujnikaTempHMI(DS_1,&HMI_D1_ERROR);
  BladCzujnikaTempHMI(DS_2,&HMI_D2_ERROR);
  BladCzujnikaTempHMI(DS_3,&HMI_D3_ERROR);
 

  V1_Pomiar();

  MAX4466_pomiar();

  //Odbieranie zaptań serwera i przypisywanie wartości do rejestrów
  mb.task();           

  //Rejestry DC18B20
  mb.Hreg(REG_TEMP_1 ,  DS_1x100); // do rejestru REG_TEMP przypisuje DS_1x100
  mb.Hreg(REG_TEMP_2 ,  DS_2x100);
  mb.Hreg(REG_TEMP_3 ,  DS_3x100);
  
  mb.Hreg(REG_Alarm_1 , Alarm_1);
  mb.Hreg(REG_Alarm_2 , Alarm_2);
  mb.Hreg(REG_Alarm_3 , Alarm_3);

  mb.Hreg(REG_HMI_D1_ERROR,HMI_D1_ERROR); 
  mb.Hreg(REG_HMI_D2_ERROR,HMI_D2_ERROR); 
  mb.Hreg(REG_HMI_D3_ERROR,HMI_D3_ERROR); 
  
  mb.Hreg(REG_MaxDS_1,MaxDS_1);
  mb.Hreg(REG_MinDS_1,MinDS_1);
  mb.Hreg(REG_MaxDS_2,MaxDS_2);
  mb.Hreg(REG_MinDS_2,MinDS_2);
  mb.Hreg(REG_MaxDS_3,MaxDS_3);
  mb.Hreg(REG_MinDS_3,MinDS_3);
  mb.Hreg(REG_IleCzujnikow , LiczbaDS18);

  //Rejestry LV53L1X
  mb.Hreg(REG_VL, mm);
  mb.Hreg(REG_Alarm_VL,Alarm_VL);
  mb.Hreg(REG_IleDetali,IleDetali);
  mb.Hreg(REG_VLMaxPomiar,MaxPomiar);
  mb.Hreg(REG_VLMinPomiar,MinPomiar);

  //Rejestry MAX4466
  mb.Hreg(REG_MaxAnalowgowyOdczyt,MaxAnalowgowyOdczyt); 
  mb.Hreg(REG_MaxOdczytFiltr,MaxOdczytFiltr);
  mb.Hreg(REG_PrzekroczenieWartosc,PrzekroczenieWartosc);
  mb.Hreg(REG_MaxAlarm,MaxAlarm); 

  }
}

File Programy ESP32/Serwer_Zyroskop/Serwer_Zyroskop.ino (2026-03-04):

#include <Arduino.h>
#include <Wire.h>
#include <Adafruit_Sensor.h>
#include <GY521.h>

//Biblioteka do Wifi i Modbus TCP/IP
#include <WiFi.h>
#include <ModbusIP_ESP8266.h>   

#define SDA 21
#define SCL 22

// KONFIGURACJA SIECI 
const char* ssid = "MikroTik";     // Nazwa sieci WiFi
const char* pass = "12345678";    // Haslo sieci WiFi

// Statyczne IP 
IPAddress local_IP(192,168,0,252);  // Adres ESP32
IPAddress gateway(192,168,0,1);      // Brama (router)
IPAddress subnet(255,255,255,0);     // Maska sieci

int I2C_speed = 400000;

GY521 sensor(0x68);
ModbusIP mb;   
//GRYRO
float ax, ay, az;
float gx, gy, gz;

int16_t ax_1000, ay_1000, az_1000;
int16_t gx_1000, gy_1000, gz_1000;

float t = 0;
int32_t tx100 = 0;

//kalibracja żyroskopu
int probki = 50;
float gx_off = 0;
float gy_off = 0;
float gz_off = 0;
float pgx_off = 0;
float pgy_off = 0;
float pgz_off = 0;

//kalibracja akcelerometru
float ax_off = 0;
float ay_off = 0;
float az_off = 0;
float pax_off = 0;
float pay_off = 0;
float paz_off = 0;


const int16_t REG_ax_1000 = 0;
const int16_t REG_ay_1000 = 1;
const int16_t REG_az_1000 = 2;
const int16_t REG_gx_1000 = 3;
const int16_t REG_gy_1000 = 4;
const int16_t REG_gz_1000 = 5;
const int16_t REG_tx100 = 6;

uint32_t CzasGY = 0;
uint32_t pCzasGY = 0;


void GYRO_ACCE(){
  CzasGY = millis();
  if(CzasGY - pCzasGY >= 100){
  
   pCzasGY = CzasGY;

   sensor.read();
   ax = sensor.getAccelX() - pax_off;
   ay = sensor.getAccelY() - pay_off;
   az = sensor.getAccelZ() - paz_off;
   gx = sensor.getGyroX() - pgx_off;
   gy = sensor.getGyroY() - pgy_off;
   gz = sensor.getGyroZ() - pgz_off;
   t = sensor.getTemperature();
  
   ax_1000  = ax * 1000;
   ay_1000  = ay * 1000;
   az_1000  = az * 1000;
   gx_1000  = gx * 100;
   gy_1000  = gy * 100;
   gz_1000  = gz * 100;
   tx100    = t * 100;



  Serial.println("\n\tAkcelerometr\t\tŻyroskop\t\tTemperatura");
  Serial.println("\tax\tay\taz\tgx\tgy\tgz\t   T");

  Serial.print('\t');
  Serial.print(ax, 3);
  Serial.print('\t');
  Serial.print(ay, 3);
  Serial.print('\t');
  Serial.print(az, 3);
  Serial.print('\t');
  Serial.print(gx, 3);
  Serial.print('\t');
  Serial.print(gy, 3);
  Serial.print('\t');
  Serial.print(gz, 3);
  Serial.print('\t');
  Serial.print(t, 3);
  Serial.println();

  }


}

void setup() {

  Serial.begin(115200);
  delay(500);
  Wire.begin(SDA, SCL);
  Wire.setClock(I2C_speed);
  delay(500);
  
  gx_off = gy_off = gz_off = 0;
  ax_off = ay_off = az_off = 0;

  while (sensor.wakeup() == false) {
    Serial.println("Nie znaleziono GY521");
    }
    
  for (int i = 0;i<probki;i++){
    sensor.read();
   gx_off = sensor.getGyroX() + gx_off;
   gy_off = sensor.getGyroY() + gy_off;
   gz_off = sensor.getGyroZ() + gz_off;
  
   ax_off = sensor.getAccelX() + ax_off;
   ay_off = sensor.getAccelY() + ay_off;
   az_off = sensor.getAccelZ() + az_off;

  delay(100);
  }

  pgx_off= gx_off/probki;
  pgy_off= gy_off/probki; 
  pgz_off= gz_off/probki;
  pax_off = ax_off/probki;
  pay_off = ay_off/probki;
  paz_off = az_off/probki - 1.0f;
  Serial.print(gx_off);
  Serial.println("\t");
  Serial.print(gy_off);
  Serial.println("\t");
  Serial.print(gz_off);
  Serial.println("\t");

  
  
 if (!WiFi.config(local_IP, gateway, subnet)) {

    Serial.println("Blad konfiguracji statycznego IP!");
  }

  WiFi.begin(ssid, pass);
  delay(1000);

  while (WiFi.status() != WL_CONNECTED) 
  { delay(500); 
  Serial.print("."); 
  }
  Serial.print("\nESP32 IP: "); 
  Serial.println(WiFi.localIP());

  // Start serwera Modbus
  mb.server();
  
  // Wartości Początkowe rejestrów / 7
  mb.addHreg(REG_ax_1000, 0);
  mb.addHreg(REG_ay_1000, 0);
  mb.addHreg(REG_az_1000, 0);
  mb.addHreg(REG_gx_1000, 0);
  mb.addHreg(REG_gy_1000, 0);
  mb.addHreg(REG_gz_1000, 0);
  mb.addHreg(REG_tx100, 0); 
}

void loop() {

  GYRO_ACCE();

  mb.task();                  
  mb.Hreg(REG_ax_1000, ax_1000);
  mb.Hreg(REG_ay_1000, ay_1000);
  mb.Hreg(REG_az_1000, az_1000);
  mb.Hreg(REG_gx_1000, gx_1000);
  mb.Hreg(REG_gy_1000, gy_1000);
  mb.Hreg(REG_gz_1000, gz_1000);
  mb.Hreg(REG_tx100,    tx100); 
  
}
